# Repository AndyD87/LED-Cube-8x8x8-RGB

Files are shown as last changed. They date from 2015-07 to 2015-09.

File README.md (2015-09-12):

# LED-Cube-8x8x8-RGB
LED-Cube Mikrocontroller Project
[Video of build Cube](https://www.youtube.com/watch?v=Oi0ap_jhWTA)
Next commit will comming soon. I'm reworking the code and prepare a SMD based LED-Cube.

## Notes
- LED-Cube with 512 RGB-LEDs in 8x8x8
- Controlled by a Microchip Microcontroller PIC18F4420
- Data for LED lighting is read from SD-Card over SPI
- Cube can be accessed from external source over UART.

## Background
Project was created in year 2009. It was my first bigger project i made.
Now it is getting reactivated, so i decided to publish it on github for a better organisation.

Because it was my first project, i had not that much expirience in how to program.
The code works great but it's still less documentated and has a chaotical structure. 
This get changed now!

## Bugs
- FTDI Chip don't work at the moment ( Hardware ) 

## ToDo
- Optimze the coding-style
- Switch microcontroller from PIC18F4420 to PIC18F4520 because of bigger Flash 
- Documentation!
- Support more SD-Cards by adding SDHC-Protocoll
- make API more simple.
- Make Sources independent from Cube x-y-z size

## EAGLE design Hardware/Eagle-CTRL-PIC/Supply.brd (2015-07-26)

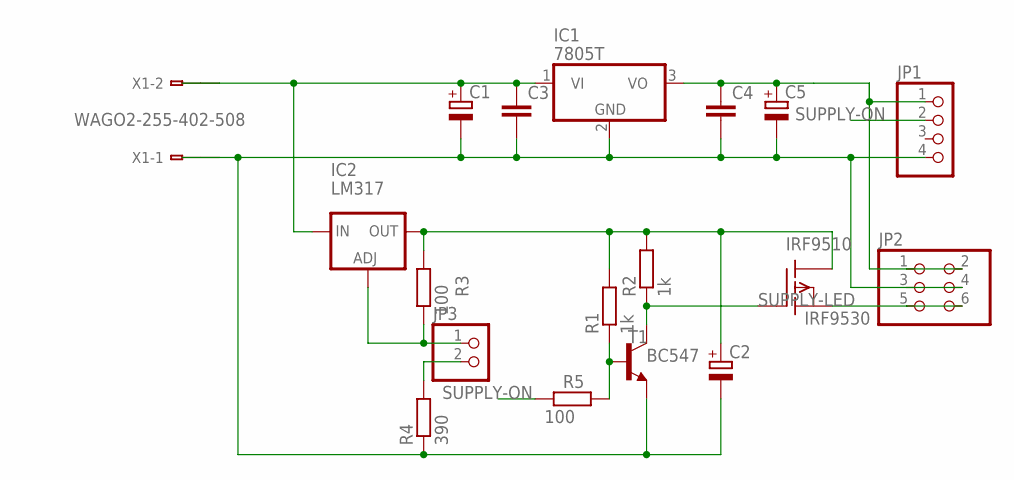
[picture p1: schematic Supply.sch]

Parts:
C1, C2: CPOL-EUE5-10.5; E5-10,5
C3, C4: C-EU050-024X044; C050-024X044
C5: CPOL-EUE2,5-6E; E2,5-6E
IC1: 7805T; TO220H
IC2: LM317; 317TL
IRF9510: IRF9530; TO220
JP1: PINHD-1X4; 1X04
JP2: PINHD-2X3; 2X03
JP3: PINHD-1X2; 1X02
R1, R2: 1k; 0207/7
R3, R5: 100; 0207/7
R4: 390; 0207/7
T1: BC547; TO92-CBE
X1: WAGO2-255-402-508; 255-402-508

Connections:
unnamed: C1.+, C3.1, IC1.1 (VI), IC2.3 (IN), X1.B2 (B1)
unnamed: IC2.1 (ADJ), JP3.1, R3.1
unnamed: C4.1, C5.+, IC1.3 (VO), JP1.1, JP2.1, JP2.2
unnamed: R1.1, R5.2, T1.B
unnamed: C1.-, C2.-, C3.2, C4.2, C5.-, IC1.2 (GND), JP1.4, JP2.3, JP2.4, R4.1, T1.E, X1.B1
unnamed: IRF9510.1 (G), R2.1, T1.C
unnamed: C2.+, IC2.2 (OUT), IRF9510.2 (D), R1.2, R2.2, R3.2
unnamed: JP3.2, R4.2
SUPPLY-LED: IRF9510.3 (S), JP2.5, JP2.6
SUPPLY-ON: JP1.2, R5.1

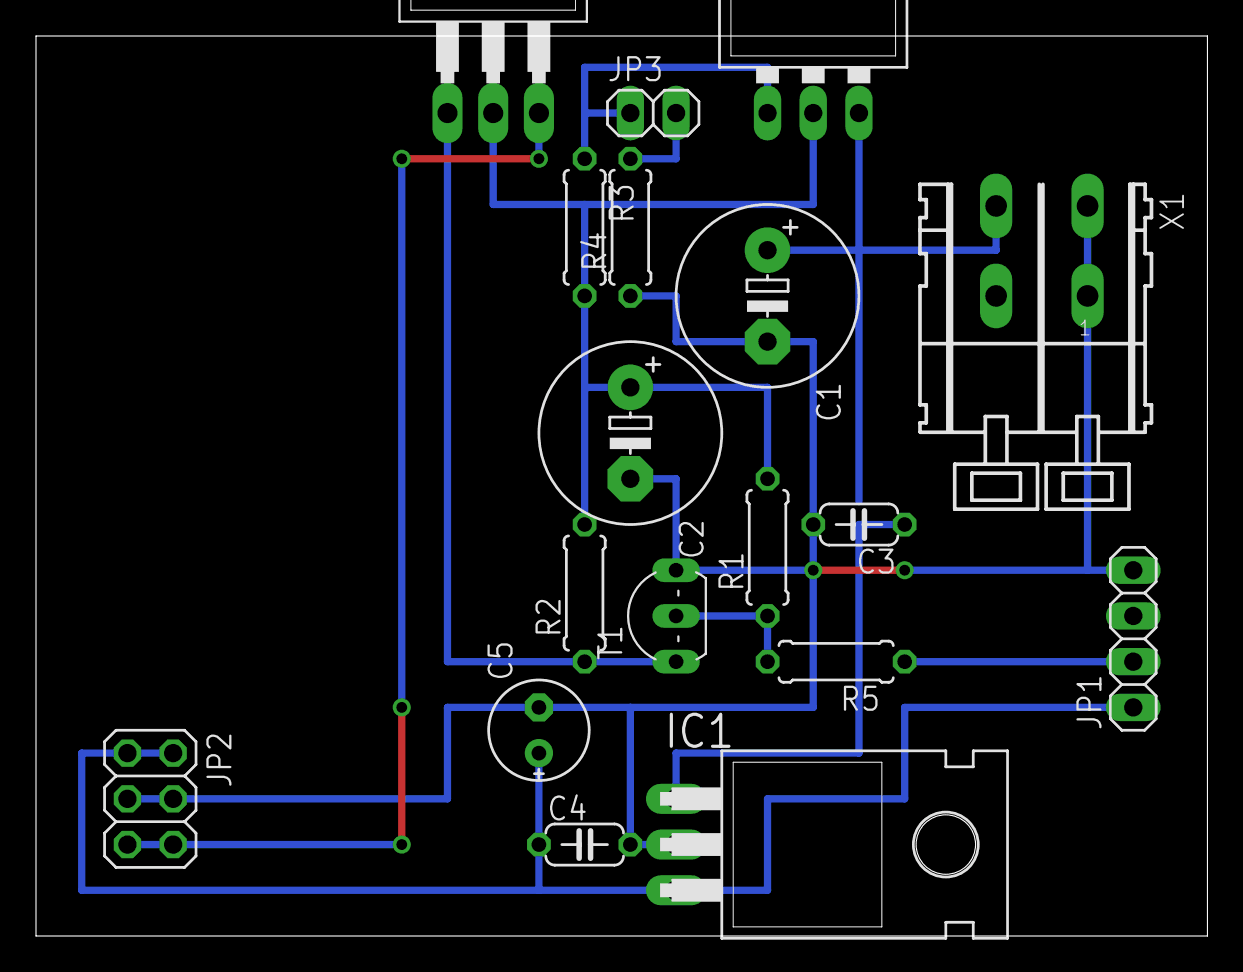
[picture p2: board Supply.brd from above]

Board: 2 copper layers, 65.1 x 50.0 mm, 18 parts (0 on the bottom side), 10 nets.

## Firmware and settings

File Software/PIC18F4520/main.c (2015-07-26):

/**
 * @mainpage LED-Cube Project
 * @file    main.c
 * @author  Andreas Dirmeier
 * @version 0.01
 *  
 * @brief   main file, starting cube and handle interrupts
 */

#include "config.h"
#include "cube/cube_main.h"

unsigned char level_counter=0; /**< Counter for Writinge out the LED-Level*/
unsigned char timer_counter=0; /**< Counts timer-interupts of 1ms until delay reached */

extern unsigned char delay_ms; /**< delay in ms until event gets called */

/**
 * @brief Main interrupt-routine
 */ 
void isr_3(void){
	//Timer 1ms
	if(PIR2 & 0x02){
		TMR3H = 0xcf;
		if(timer_counter >= delay_ms){
			timer_counter = 0;
			if(!cube_timer_interrupt()) 
        T3CONbits.TMR3ON = 0;
		}
		else {
			timer_counter ++;
		}
		PIR2 &= 0xfd;
	}
	if(PIR1 & 0x01){
		INTCONbits.GIE=0;
		TMR1H=0xf0;
		PIR1 &= 0xfe;
		Cube_WriteLevel(level_counter);
    //setup next level
		if(level_counter>14){
			level_counter = 0;
			Leveldat=0;
		}
		else {
			level_counter++;;
			Leveldat=1;
		}
		INTCONbits.GIE=1;
	}
	if(PIR1 & 0x20){
		PIE1 &= 0xdf;
		PIR1 &= 0xdf;
		TXREG = Cube_ParseCmd(RCREG);
		PIE1 |= 0x20;
	}
}

/**
 * @brief high priority interrupt, calles the main interrupt routine
 */ 
void interrupt high_priority isr1( void )
{  isr_3();}

/**
 * @brief low priority interrupt, calles the main interrupt routine
 */ 
void interrupt low_priority isr2( void )
{  isr_3();}

/**
 *
 */
void main ()
{
  LoadConfig();
	init_cube();
  //do nothing, cube is interrupt controled
	while(1);
}

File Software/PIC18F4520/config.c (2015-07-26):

/**
 * @file    config.c
 * @author  Andreas Dirmeier
 * @version 0.01
 *  
 * @brief   Configuration Functions for uController
 */
#include "CONFIG.h"

void LoadConfig()
{
	PORTA = 0;
	LATA = 0;
	ADCON1 = 0x0f;
	CMCON = 0x07;
	TRISA = 0xff;

	PORTB = 0;
	LATB = 0;
	TRISB = 0;

	PORTC = 0;
	LATC = 0;
	TRISC = 0xd3;

	PORTD = 0;
	LATD = 0;
	TRISD = 0;
	
	PORTE = 0;
	LATE = 0;
	TRISE = 0x00;

	OSCCON = 0x8c;
	RCON = 0x93;
	INTCON = 0xc0;
	INTCON2 = 0x00;
	INTCON3 = 0x00;
	PIE1 = 0x23;
	PIE2 = 0x02;
	IPR1 = 0x21;
	IPR2 = 0x00;
	
	TXSTA = 0x24;
	RCSTA = 0x90;
	BAUDCON = 0x00;
	SPBRG = 64;
	
	T3CON = 0xc1;
	T1CON = 0x01;
}

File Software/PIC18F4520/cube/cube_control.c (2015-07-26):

/**
 * @file    cube_control.c
 * @author  Andreas Dirmeier
 * @version 0.01
 *  
 * @brief   Cube output functions to LEDs
 */
#include "cube_control.h"


#define Clock     PORTBbits.RB4
#define Switch    PORTBbits.RB5
#define CLK       PORTBbits.RB6
#define Leveldat  PORTBbits.RB7

extern unsigned char led[3][64];
extern unsigned char delay_ms;

void Cube_WriteLevel (unsigned char stage){
	unsigned char counter = 0;
	unsigned char stage_temp, blueL, blueH, tmp_blue;
	stage_temp = (stage)*4;
	if(stage & 0x01)
		stage_temp -= 4;
	else 	stage_temp++;
	while(counter<8)
	{
		tmp_blue = led[2][stage_temp + counter];
		blueL =  tmp_blue & 0x01       | (tmp_blue >> 1) & 0x02 |
			(tmp_blue >> 2) & 0x04 | (tmp_blue >> 3) & 0x08;
		blueH = (tmp_blue >> 1) & 0x01 | (tmp_blue >> 2) & 0x02 |
			(tmp_blue >> 3) & 0x04 | (tmp_blue >> 4) & 0x08;
		PORTD = led[1][stage_temp + counter];
		PORTB = (PORTB & 0xf0) | blueH;
		Clock = 1;
		Clock = 0;
		PORTD = led[0][stage_temp + counter];
		PORTB = (PORTB & 0xf0) | blueL ;
		Clock = 1;
		Clock = 0;
		counter+=2;
	}
	PORTB = (PORTB & 0x9f) | 0x60;
	PORTB &= 0x9f;
}
void cube_reset(){
	unsigned char counter;
	PORTD = 0;
	PORTB = 0;
	Leveldat=1;
	for(counter=0;counter<64;counter++)
	{
		led[0][counter] = 0;
		led[1][counter] = 0;
		led[2][counter] = 0;
		Clock = 1;
		Clock = 0;
		CLK = 1;
		CLK = 0;
	}
}

void cube_setDelay(unsigned char delay){
	delay_ms = delay;
}
